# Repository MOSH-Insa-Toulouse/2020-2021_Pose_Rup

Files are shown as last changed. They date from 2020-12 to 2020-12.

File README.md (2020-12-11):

# 2020-2021_Pose_Rup
Shield comportant un capteur de gaz développé à l'AIME pour la Arduino UNO

## SMALL DESCRIPTION
Ce shield permet l'exploitation directe de la mesure du gas dans un pièce grâce au capteur de gas développé en salle blanche à l'AIME.
Une LED rouge permet de prévenir lutilisateur d'une trop mauvaise qualité de l'air.
Un espace a été spécialement réservé pour inclure la carte de développement du module RN2483A de drazzy.com.

---

## INCLUDE IN THE DESIGN

- [x] Gas sensor réalisé à l'AIME
- [x] Capteur de température pour mesurer la température opérationelle du capteur de gas
- [x] Circuit de traitement et amplification du signal du capteur de gaz
- [x] LED rouge pour prévenir l'utilisateur d'un danger / mauvaise qualité de l'air
- [x] Socket pour venir fixer la carte intégrant le module LoRa et son antenne
- [x] 2 transistors NPN permettant d'allumer ou d'éteindre les alimentations du circuit capteur (entre 2 prises de mesure) en utilisant la pin 3 de l'Arduino

## Bill Of Materials

| Components | Reference |
|:---:|:---:|
| Gas sensor | GSWO3AIME20 (built at AIME) |
| Operational Amplifier | LTC1050 |
| NPN transistor | P2N2222A |
| LoRa module | RN2483 |
| External Board for LoRa module | Drazzy.com RN2483 Breakout Board |

---

## Tools used

### KiCad

[KiCad EDA - Schematic Capture & PCB Design Software](https://kicad-pcb.org/), version: 5.1.7

Open source EDA / electronics CAD software for Windows, macOS and Linux.

## Electrical diagram

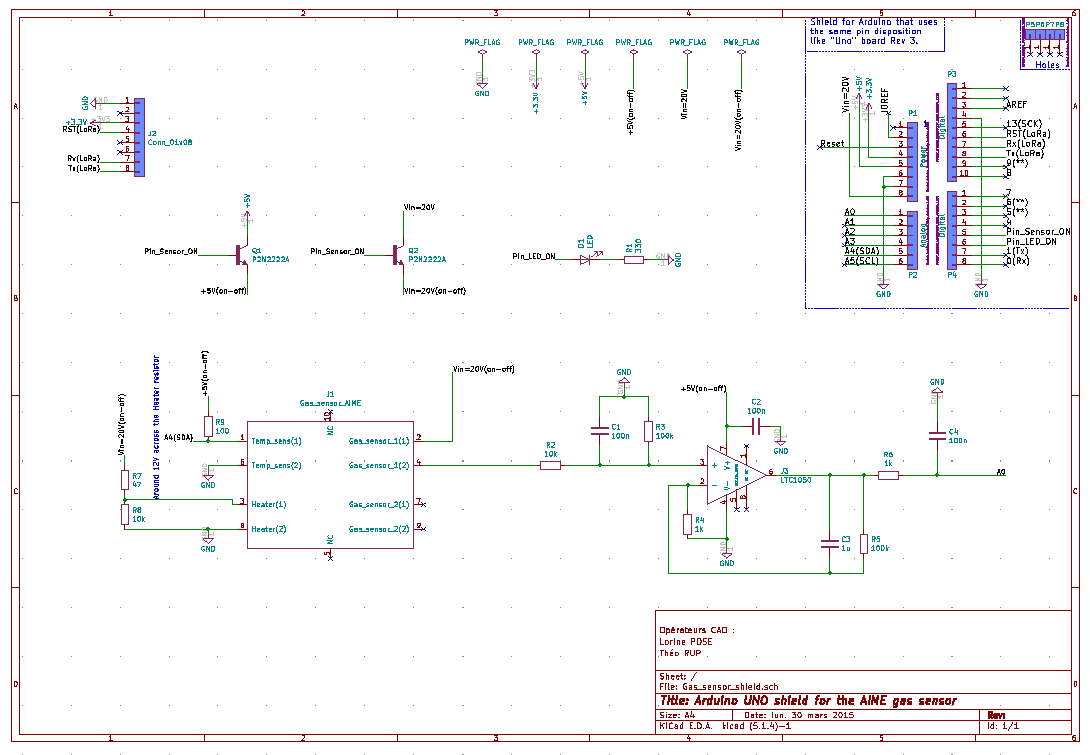
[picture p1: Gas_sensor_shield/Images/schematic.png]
Schematic


## Components placement

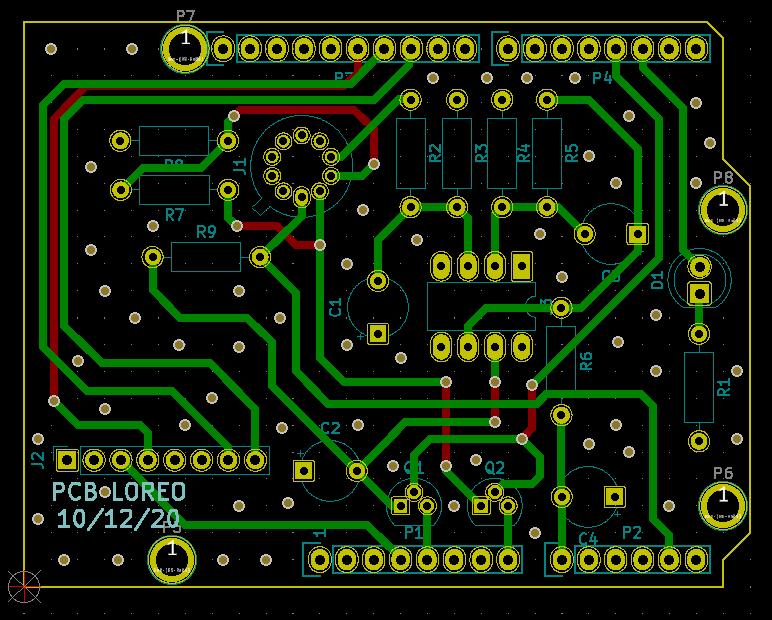
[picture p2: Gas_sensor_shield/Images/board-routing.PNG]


## 3D view

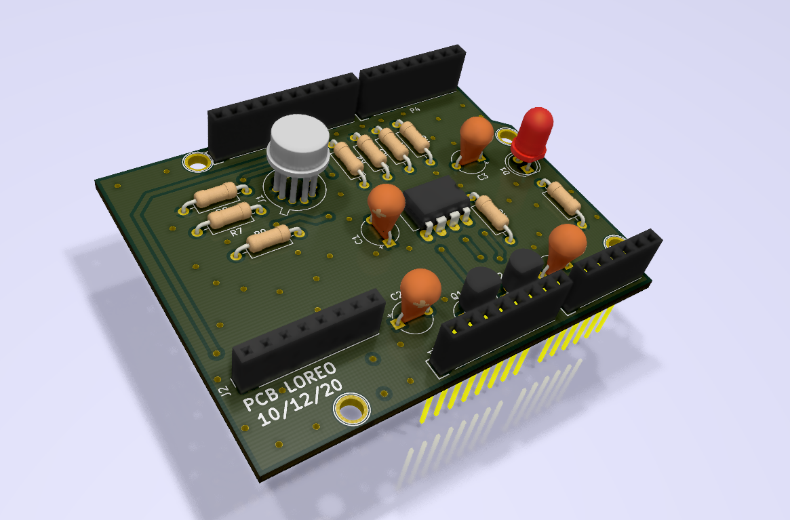
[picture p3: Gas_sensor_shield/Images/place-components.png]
Place components


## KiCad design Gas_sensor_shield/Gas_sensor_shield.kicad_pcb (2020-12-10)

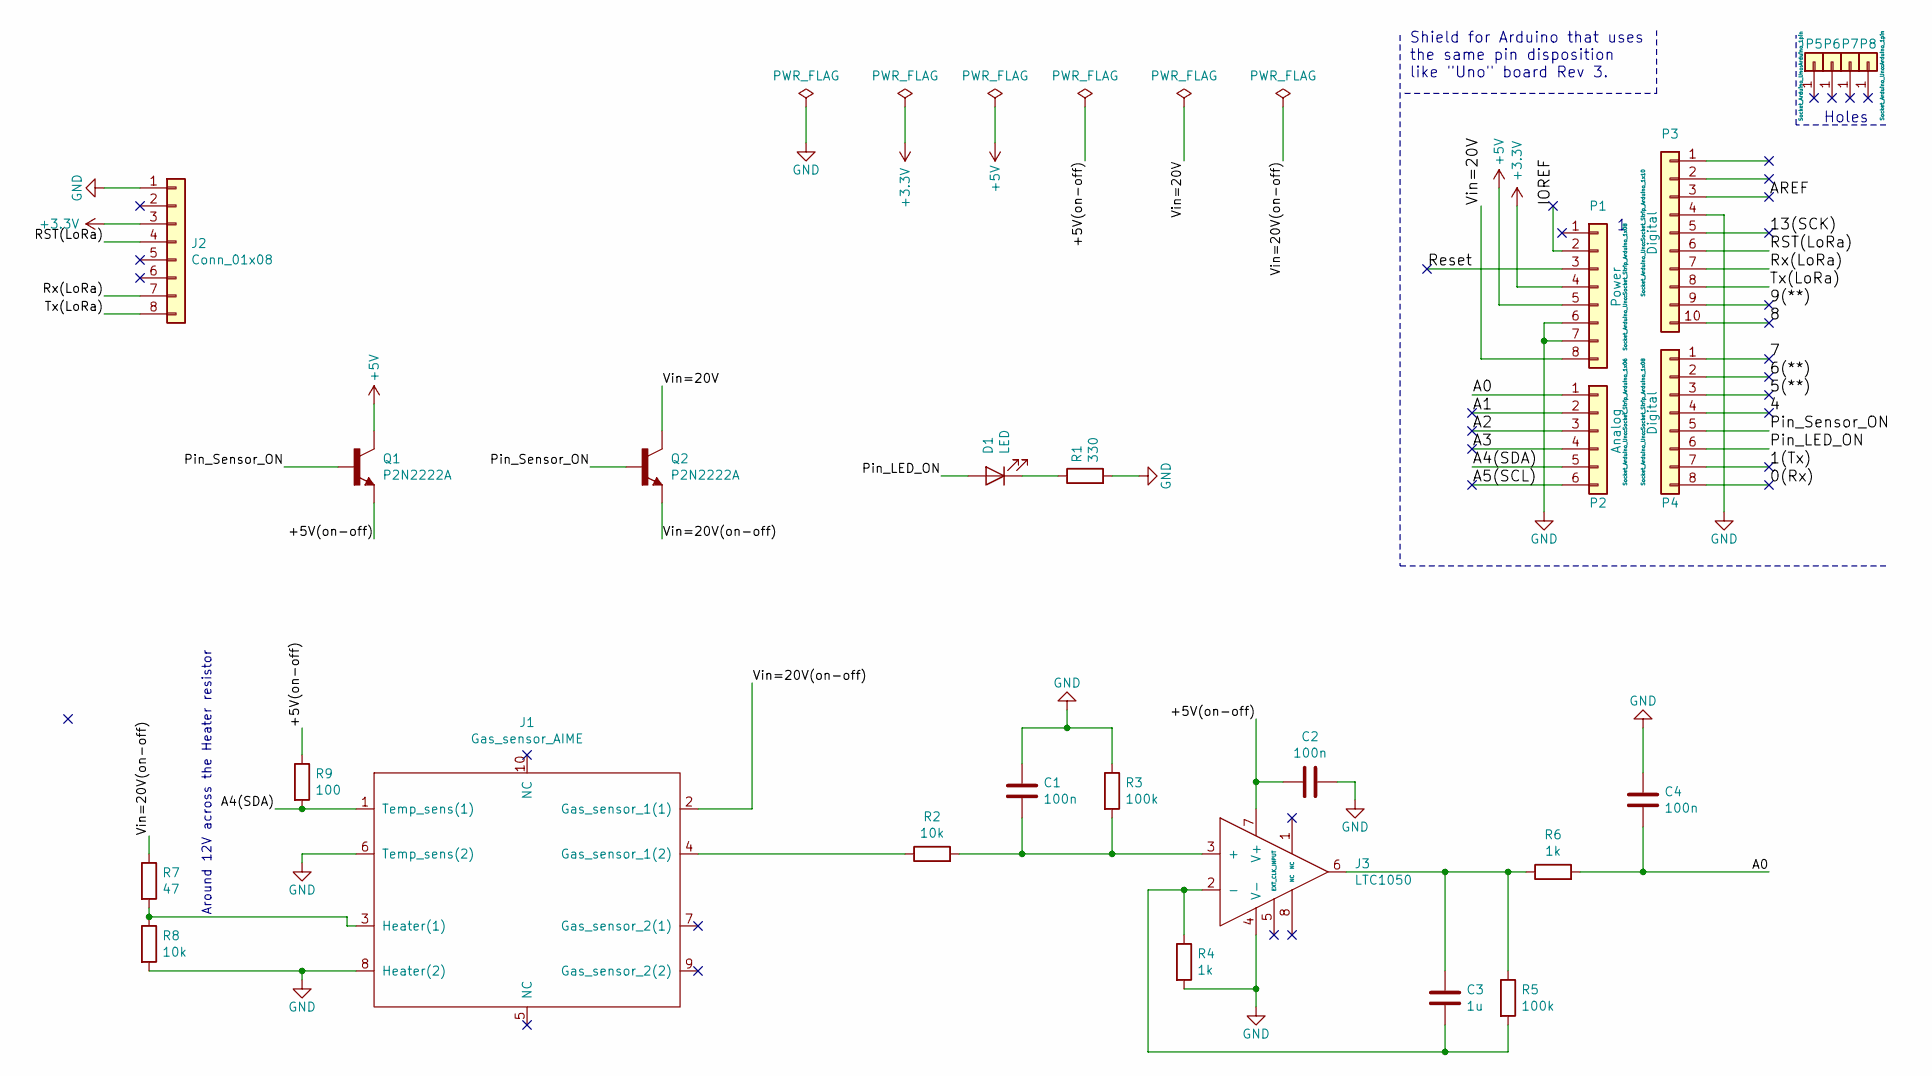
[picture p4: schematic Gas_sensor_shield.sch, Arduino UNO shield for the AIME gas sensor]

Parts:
C1, C2, C4: 100n; CP_Radial_Tantal_D5.5mm_P5.00mm
C3: 1u; CP_Radial_Tantal_D5.5mm_P5.00mm
D1: LED; LED_D5.0mm
J1: Gas_sensor_AIME; Package_TO-5-10_Window
J2: Conn_01x08; PinSocket_1x08_P2.54mm_Vertical
J3: LTC1050; Package_DIP-8_W7.62mm_LongPads
P1: Power; Socket_Strip_Arduino_1x08
P2: Analog; Socket_Strip_Arduino_1x06
P3: Digital; Socket_Strip_Arduino_1x10
P4: Digital; Socket_Strip_Arduino_1x08
P5, P6, P7, P8: CONN_01X01; Arduino_1pin
Q1, Q2: P2N2222A; Package_TO-92
R1: 330; R_Axial_DIN0207_L6.3mm_D2.5mm_P10.16mm_Horizontal
R2, R8: 10k; R_Axial_DIN0207_L6.3mm_D2.5mm_P10.16mm_Horizontal
R3, R5: 100k; R_Axial_DIN0207_L6.3mm_D2.5mm_P10.16mm_Horizontal
R4, R6: 1k; R_Axial_DIN0207_L6.3mm_D2.5mm_P10.16mm_Horizontal
R7: 47; R_Axial_DIN0207_L6.3mm_D2.5mm_P10.16mm_Horizontal
R9: 100; R_Axial_DIN0207_L6.3mm_D2.5mm_P10.16mm_Horizontal

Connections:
+3V3: J2.3, P1.4
+5V: P1.5, Q1.3
/0(Rx): P4.8
/1(Tx): P4.7
/4: P4.4
/5(**): P4.3
/6(**): P4.2
/7: P4.1
/8: P3.10
/9(**): P3.9
/13(SCK): P3.5
/+5V(on-off): C2.2, J3.7 (V+), Q1.1, R9.1
/A0: C4.2, P2.1, R6.2
/A1: P2.2
/A2: P2.3
/A3: P2.4
/A4(SDA): J1.1 (Temp_sens(1)), P2.5, R9.2
/A5(SCL): P2.6
/AREF: P3.3
/IOREF: P1.2
/Pin_LED_ON: D1.2 (A), P4.6
/Pin_Sensor_ON: P4.5, Q1.2, Q2.2
/RST(LoRa): J2.4, P3.6
/Reset: P1.3
/Rx(LoRa): J2.7, P3.7
/Tx(LoRa): J2.8, P3.8
/Vin=20V: P1.8, Q2.3
/Vin=20V(on-off): J1.2 (Gas_sensor_1(1)), Q2.1, R7.1
GND: C1.1, C2.1, C4.1, J1.6 (Temp_sens(2)), J1.8 (Heater(2)), J2.1, J3.4 (V-), P1.6, P1.7, P3.4, R1.2, R3.1, R4.2, R8.2
unnamed: C1.2, J3.3 (+), R2.2, R3.2
unnamed: C3.1, J3.6, R5.1, R6.1
unnamed: C3.2, J3.2 (-), R4.1, R5.2
unnamed: D1.1 (K), R1.1
unnamed: J1.3 (Heater(1)), R7.2, R8.1
unnamed: J1.4 (Gas_sensor_1(2)), R2.1

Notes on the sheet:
Holes
Shield for Arduino that uses the same pin disposition like "Uno" board Rev 3.
Around 12V across the Heater resistor

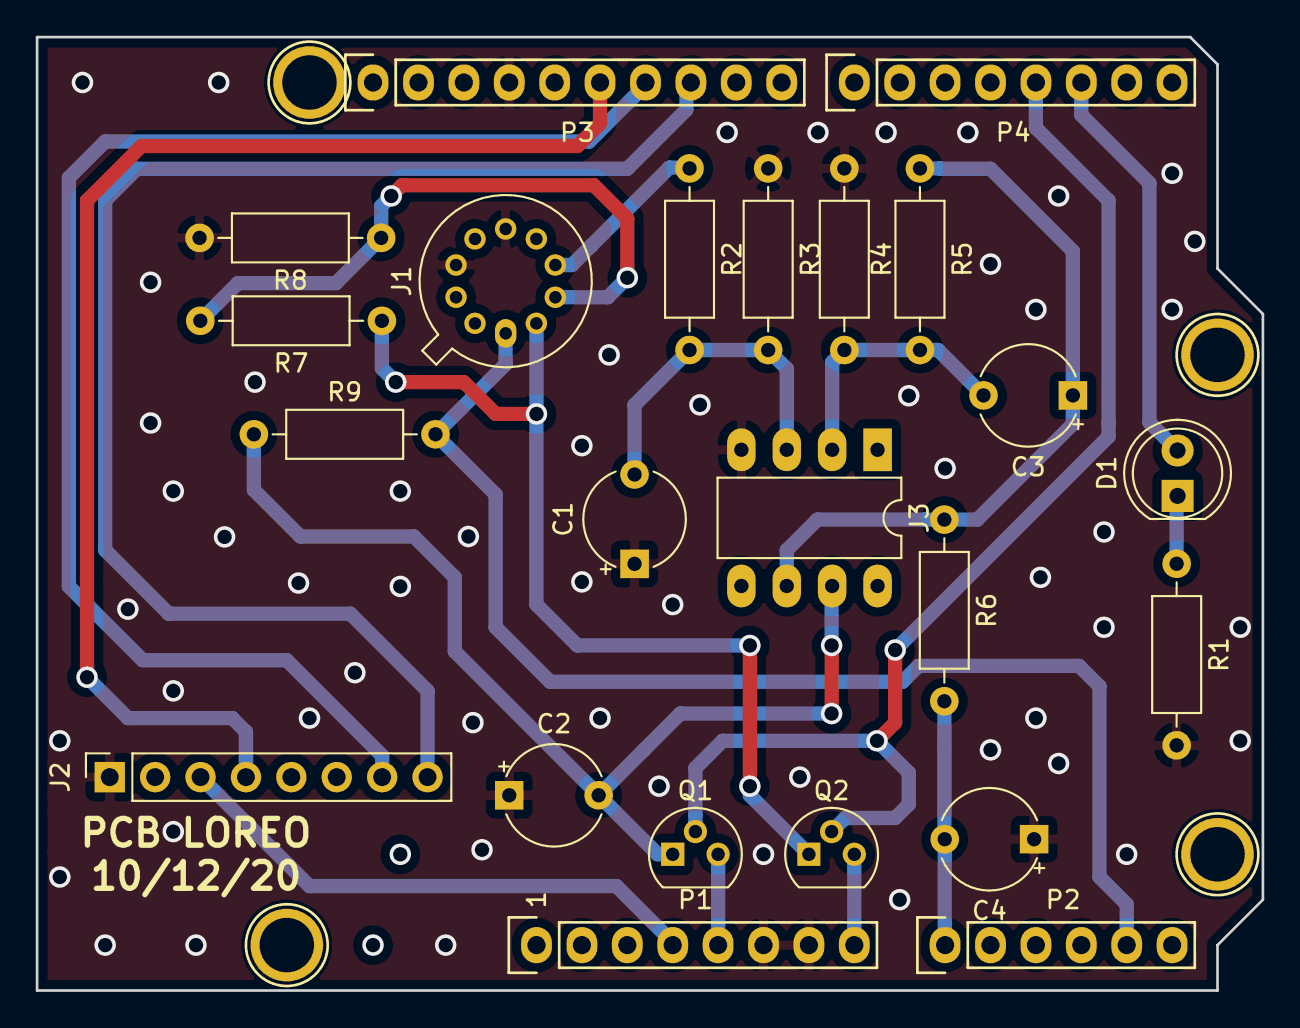
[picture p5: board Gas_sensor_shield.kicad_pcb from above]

Board: 2 copper layers, 68.6 x 53.3 mm, 27 parts (0 on the bottom side), 19 nets.

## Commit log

2020-12-07 Première version du PCB
    [Gas_sensor_shield.kicad_pcb, Gas_sensor_shield.sch]
2020-12-07 Rectification du path des images du Readme
2020-12-10 Corrections du board
    [Gas_sensor_shield.kicad_pcb, Gas_sensor_shield.sch]
2020-12-10 Correction du board
2020-12-10 Attache image board readme.md
2020-12-10 Schema modification
    [Gas_sensor_shield.sch]
2020-12-11 Add BOM
